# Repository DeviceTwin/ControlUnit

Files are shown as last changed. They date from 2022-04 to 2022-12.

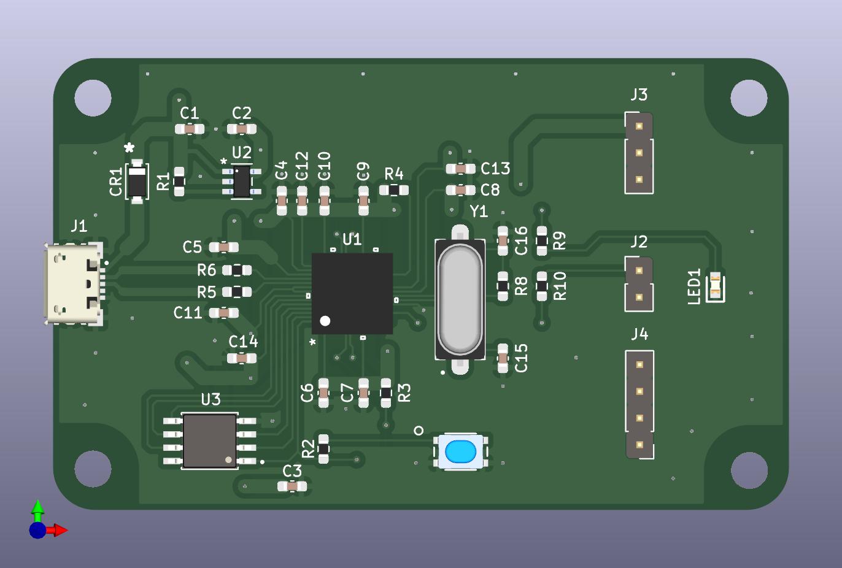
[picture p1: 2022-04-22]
Pictures/ControlUnit3DFront.jpg

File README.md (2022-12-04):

# LEDControl_HW

:one: This is my first PCB design what I ordered from real PCB factory.<br>
:two: Also this is my first PCB what I soldering using reflow owen.

Hardware of LED control unit based on:<br>
<a href="https://www.youtube.com/watch?v=kcwvuwetgEQ"
			target="_blank">Hardware Design with the RP2040: Custom PCB Based on the Raspberry Pi Pico | Digi-Key Electronics</a>

PCB design help:<br>
<a href="https://www.youtube.com/watch?v=ge6gYIENo8Q"
			target="_blank">How to Make a Raspberry Pi Compute Module 4 Carrier Board in KiCad - Part 2 | Digi-Key Electronics</a>

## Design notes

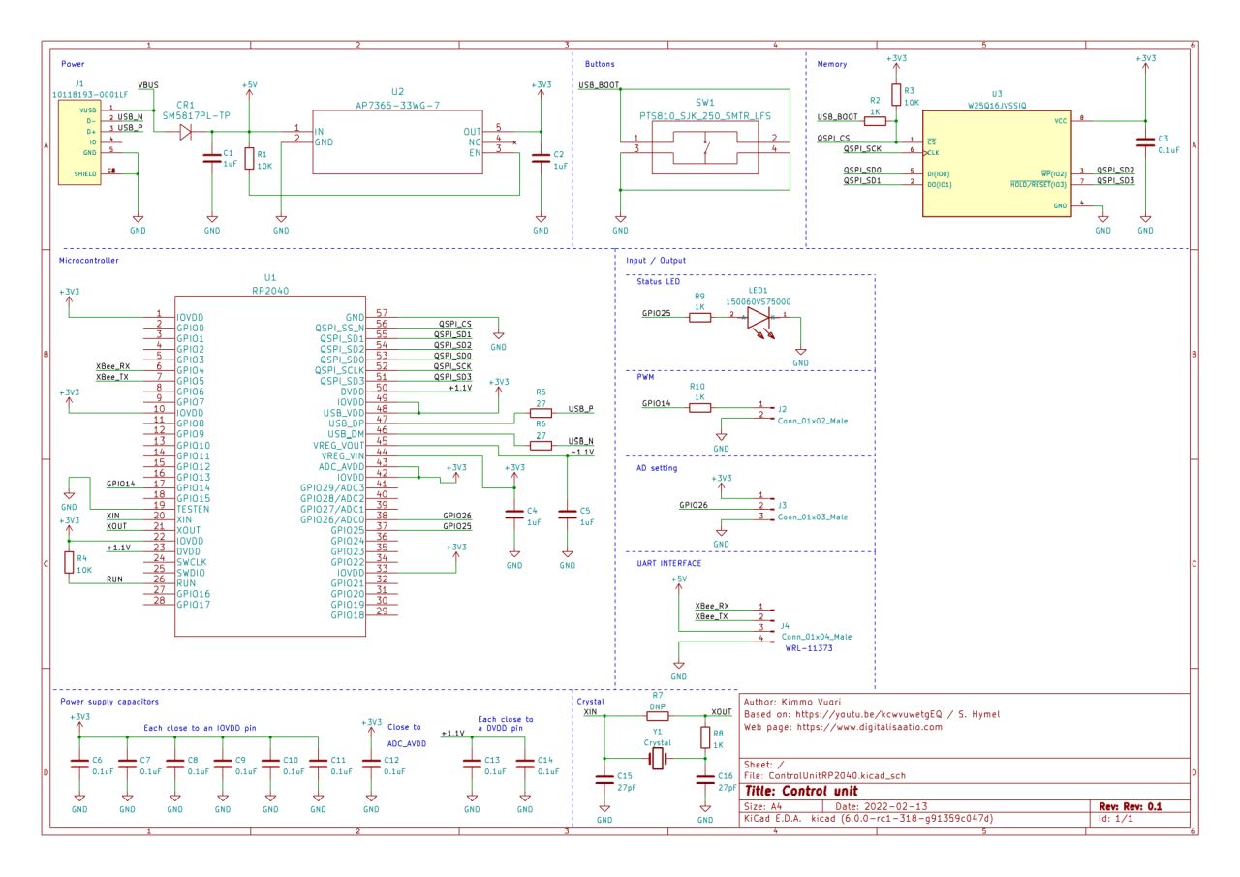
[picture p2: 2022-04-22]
Pictures/ControlUnitSchematic.jpg

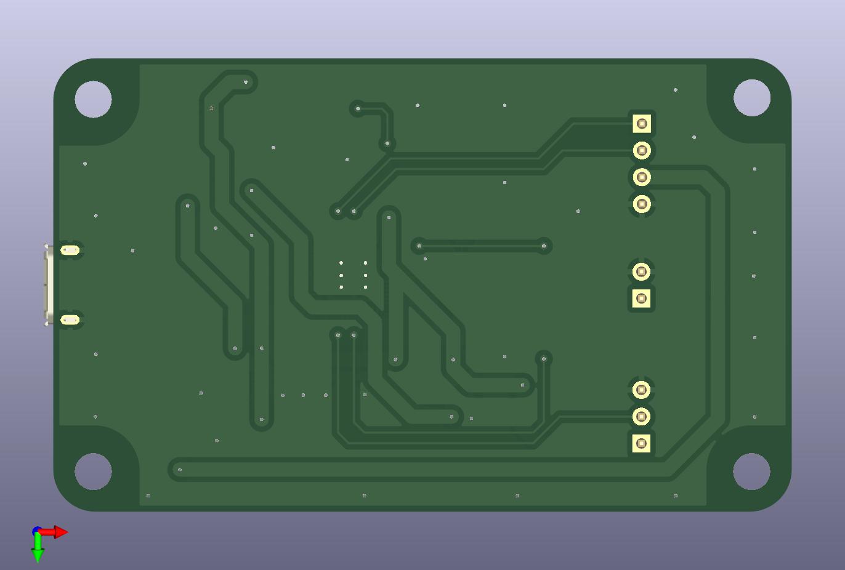
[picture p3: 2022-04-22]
Pictures/ControlUnit3DBack.jpg

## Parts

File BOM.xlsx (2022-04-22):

Reference | Quantity | Sarake1 | Sarake2 | Sarake3 | Value | Digikey | Manufacturer Product Number
C1 C2 C4 C5 | 4 | 12 | x |  | 1uF | 311-1445-1-ND | CC0603KRX5R8BB105
C15 C16 | 2 | 6 | x |  | 27pF | 399-C0603C270F3HACAUTOCT-ND | C0603C270F3HACAUTO
C3 C6 C7 C8 C9 C10 C11 C12 C13 C14 | 10 | 30 | x |  | 0.1uF | 587-1245-1-ND | TMK107BJ104KA-T
CR1 | 1 | 3 | x |  | SM5817PL-TP | SM5817PL-TPMSCT-ND | SM5817PL-TP
J1 | 1 | 3 | x |  | 10118193-0001LF | 609-4616-1-ND | 10118193-0001LF
J2 | 1 | 3 | x |  | Conn_01x02_Male | 2057-PH1-02-UA-ND | PH1-02-UA
J3 | 1 | 3 | x |  | Conn_01x03_Male | 2057-PH1-03-UA-ND | PH1-03-UA
J4 | 1 | 3 | x |  | Conn_01x04_Male | S1212EC-04-ND | PREC004SFAN-RC
LED1 | 1 | 3 | x |  | SML-310PTT86 | 511-1300-1-ND | SML-310PTT86
R1 R3 R4 | 3 | 9 | x |  | 10K | P20397TR-ND | ERJ-PB3D1002V
R2 R8 R9 R10 | 4 | 12 | x |  | 1K | P20283CT-ND | ERJ-PB3D1001V
R5 R6 | 2 | 6 | x |  | 27 | 311-27.0HRCT-ND | RC0603FR-0727RL
SW1 | 1 | 3 | x |  | PTS810_SJK_250_SMTR_LFS | CKN10503CT-ND | PTS810 SJK 250 SMTR LFS
U1 | 1 | 3 | x |  | RP2040 | 2648-SC0914(7)CT-ND | SC0914(7)
U2 | 1 | 3 | x |  | AP7365-33WG-7 | AP7365-33WG-7DICT-ND | AP7365-33WG-7
U3 | 1 | 3 | x |  | W25Q16JVSSIQ | W25Q16JVSSIQ-ND | W25Q16JVSSIQ
Y1 | 1 | 3 | x |  | Crystal | 535-10218-1-ND | ABLS-12.000MHZ-B4-T
TS391SNL | 1 | 1 | x |  | Solder paste | TS391SNL-ND | TS391SNL
Pico | 2 | 2 | x

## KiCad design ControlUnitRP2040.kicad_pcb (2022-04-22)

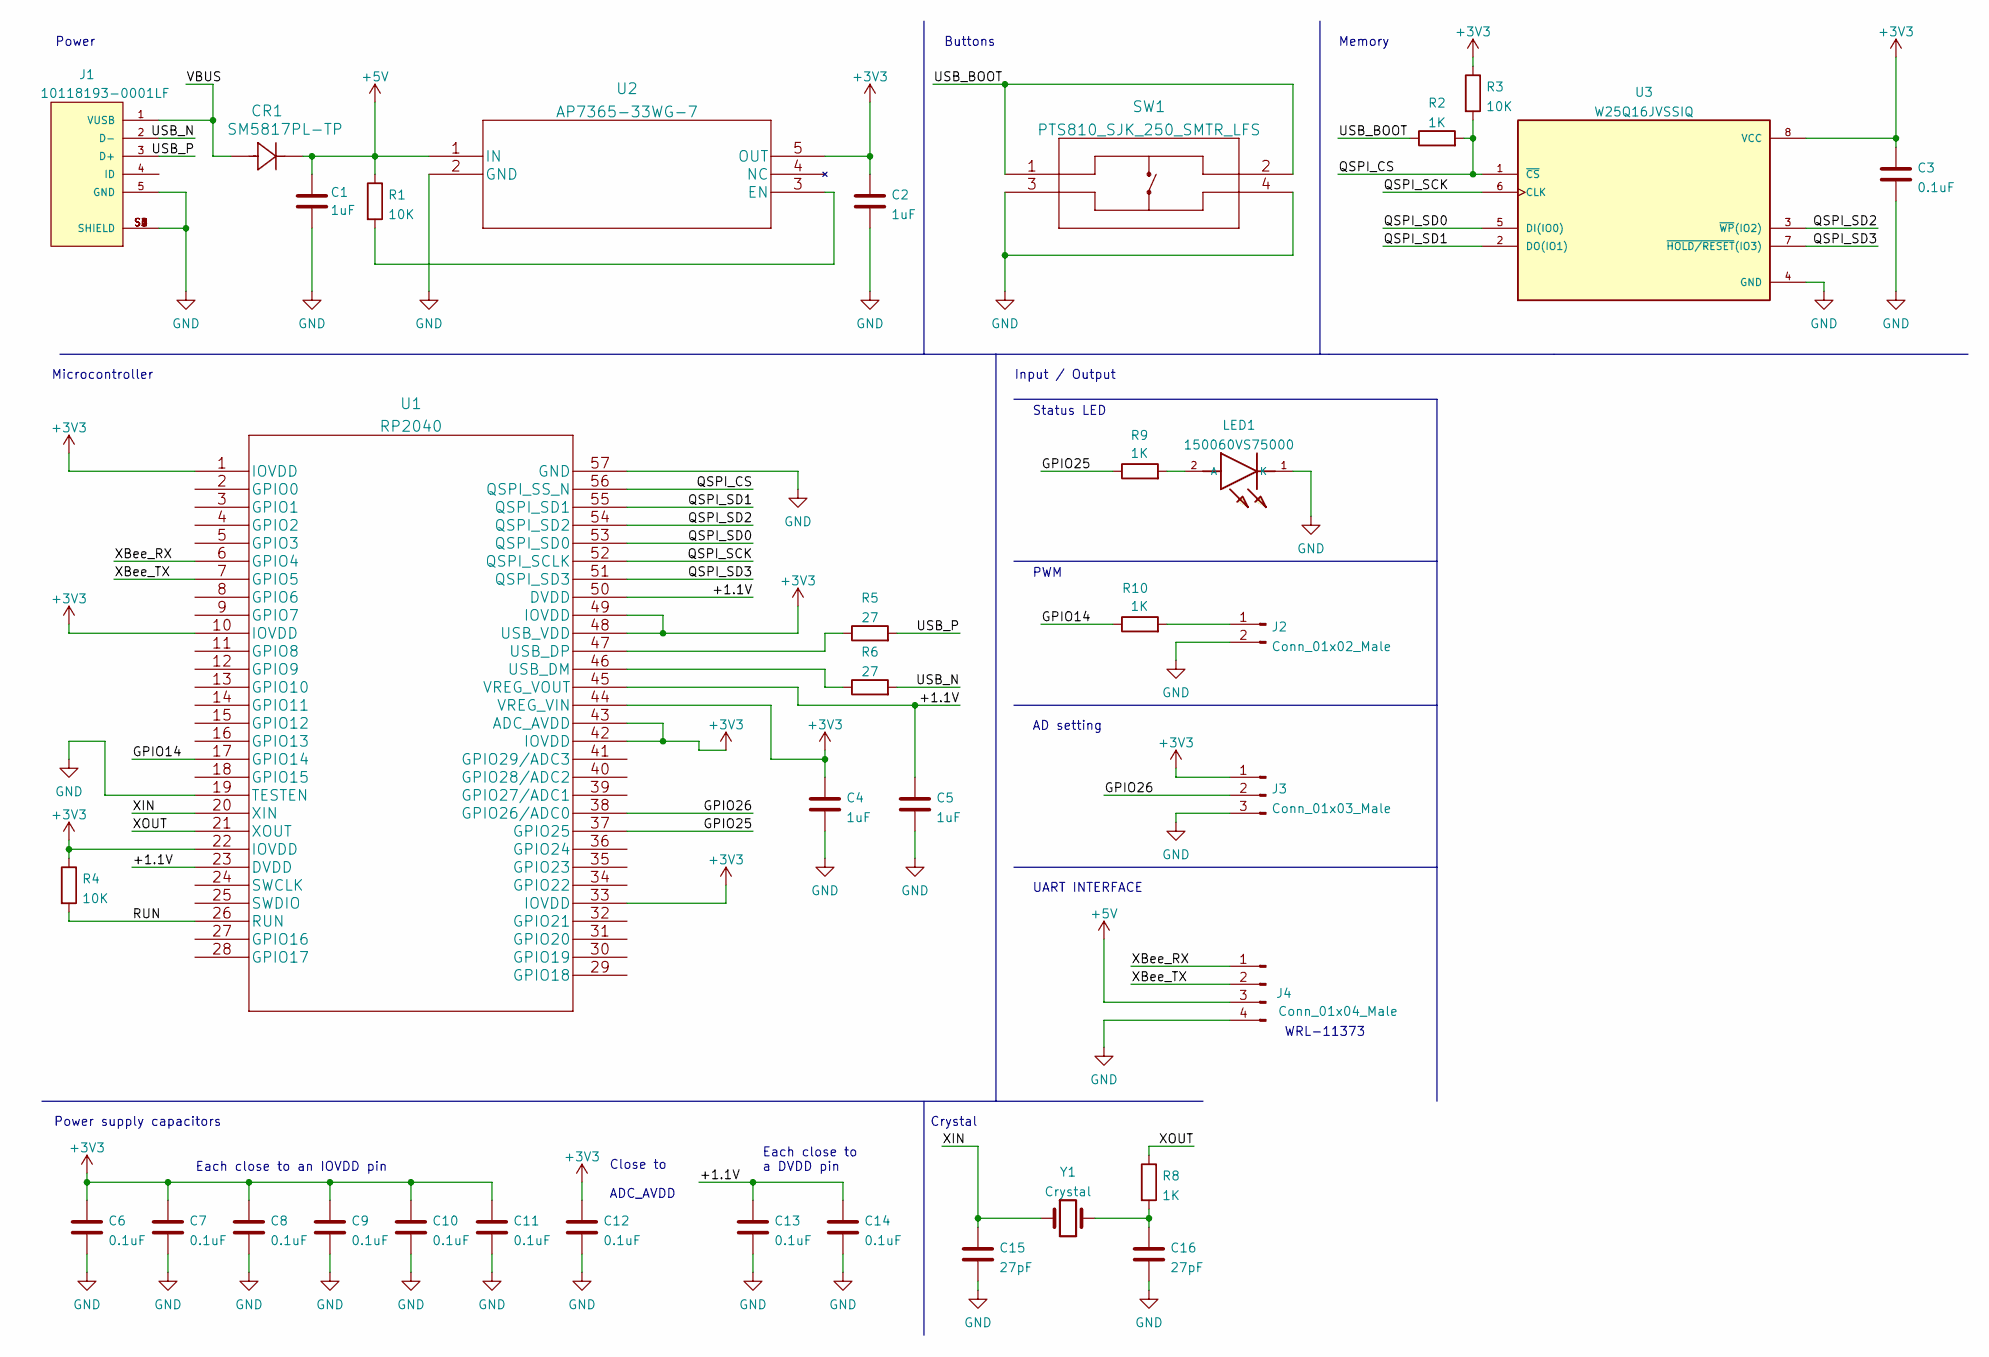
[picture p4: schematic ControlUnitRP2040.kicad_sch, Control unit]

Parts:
C1, C2, C4, C5: 1uF; C_0603_1608Metric_Pad1.08x0.95mm_HandSolder; Digikey 311-1445-1-ND
C3, C6, C7, C8, C9, C10, C11, C12, C13, C14: 0.1uF; C_0603_1608Metric_Pad1.08x0.95mm_HandSolder; Digikey 587-1245-1-ND
C15, C16: 27pF; C_0603_1608Metric_Pad1.08x0.95mm_HandSolder; Digikey 399-C0603C270F3HACAUTOCT-ND
CR1: SM5817PL-TP; Digikey SM5817PL-TPMSCT-ND
J1: 10118193-0001LF; FCI_10118193-0001LF; Digikey 609-4616-1-ND
J2: Conn_01x02_Male; PinHeader_1x02_P2.54mm_Vertical; Digikey 2057-PH1-02-UA-ND
J3: Conn_01x03_Male; PinHeader_1x03_P2.54mm_Vertical; Digikey 2057-PH1-03-UA-ND
J4: Conn_01x04_Male; PinHeader_1x04_P2.54mm_Vertical; Digikey 2057-PH1-04-UA-ND
LED1: 150060VS75000; LEDC1608X80N; Digikey 732-4980-1-ND
R1, R3, R4: 10K; R_0603_1608Metric_Pad0.98x0.95mm_HandSolder; Digikey 13-AC0603DR-0710KLCT-ND
R2, R8, R9, R10: 1K; R_0603_1608Metric_Pad0.98x0.95mm_HandSolder; Digikey P20283CT-ND
R5, R6: 27; R_0603_1608Metric_Pad0.98x0.95mm_HandSolder; Digikey 311-27.0HRCT-ND
SW1: PTS810_SJK_250_SMTR_LFS; PTS810 SJK 250 SMTR LFS; Digikey CKN10503CT-ND
U1: RP2040; Digikey 2648-SC0914(7)CT-ND
U2: AP7365-33WG-7; Digikey AP7365-33WG-7DICT-ND
U3: W25Q16JVSSIQ; SOIC127P790X216-8N; Digikey W25Q16JVSSIQ-ND
Y1: Crystal; ABLS-12.000MHZ-B4-T; Digikey 535-10218-1-ND

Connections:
+3V3: C2.1, C3.1, C4.1, C6.1, C7.1, C8.1, C9.1, C10.1, C11.1, C12.1, J3.1, R3.1, R4.1, U1.1 (IOVDD), U1.10 (IOVDD), U1.22 (IOVDD), U1.33 (IOVDD), U1.42 (IOVDD), U1.43 (ADC_AVDD), U1.44 (VREG_VIN), U1.48 (USB_VDD), U1.49 (IOVDD), U2.5 (OUT), U3.8 (VCC)
+5V: C1.1, CR1.1, J4.3, R1.1, U2.1 (IN)
/+1.1V: C5.1, C13.1, C14.1, U1.23 (DVDD), U1.45 (VREG_VOUT), U1.50 (DVDD)
/GPIO14: R10.1, U1.17 (GPIO14)
/GPIO25: R9.1, U1.37 (GPIO25)
/GPIO26: J3.2, U1.38 (GPIO26/ADC0)
/QSPI_CS: R2.2, R3.2, U1.56 (QSPI_SS_N), U3.1 (~CS)
/QSPI_SCK: U1.52 (QSPI_SCLK), U3.6 (CLK)
/QSPI_SD0: U1.53 (QSPI_SD0), U3.5 (DI(IO0))
/QSPI_SD1: U1.55 (QSPI_SD1), U3.2 (DO(IO1))
/QSPI_SD2: U1.54 (QSPI_SD2), U3.3 (~WP(IO2))
/QSPI_SD3: U1.51 (QSPI_SD3), U3.7 (~HOLD/RESET(IO3))
/RUN: R4.2, U1.26 (RUN)
/USB_BOOT: R2.1, SW1.1, SW1.2
/USB_N: J1.2 (D-), R6.2
/USB_P: J1.3 (D+), R5.2
/VBUS: CR1.2, J1.1 (VUSB)
/XBee_RX: J4.1, U1.6 (GPIO4)
/XBee_TX: J4.2, U1.7 (GPIO5)
/XIN: C15.1, U1.20 (XIN), Y1.1
/XOUT: R8.1, U1.21 (XOUT)
GND: C1.2, C2.2, C3.2, C4.2, C5.2, C6.2, C7.2, C8.2, C9.2, C10.2, C11.2, C12.2, C13.2, C14.2, C15.2, C16.2, J1.5 (GND), J1.S1 (SHIELD), J1.S2 (SHIELD), J1.S3 (SHIELD), J1.S4 (SHIELD), J1.S5 (SHIELD), J1.S6 (SHIELD), J2.2, J3.3, J4.4, LED1.1 (K), SW1.3, SW1.4, U1.19 (TESTEN), U1.57 (GND), U2.2 (GND), U3.4 (GND)
unnamed: C16.1, R8.2, Y1.2
unnamed: J2.1, R10.2
unnamed: LED1.2 (A), R9.2
unnamed: R1.2, U2.3 (EN)
unnamed: R5.1, U1.47 (USB_DP)
unnamed: R6.1, U1.46 (USB_DM)

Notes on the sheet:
Power supply capacitors
Buttons
Memory
PWM
Power
Status LED
Each close to an IOVDD pin
WRL-11373
Input / Output
Close to ADC_AVDD
Microcontroller
AD setting
Crystal
Each close to a DVDD pin
UART INTERFACE

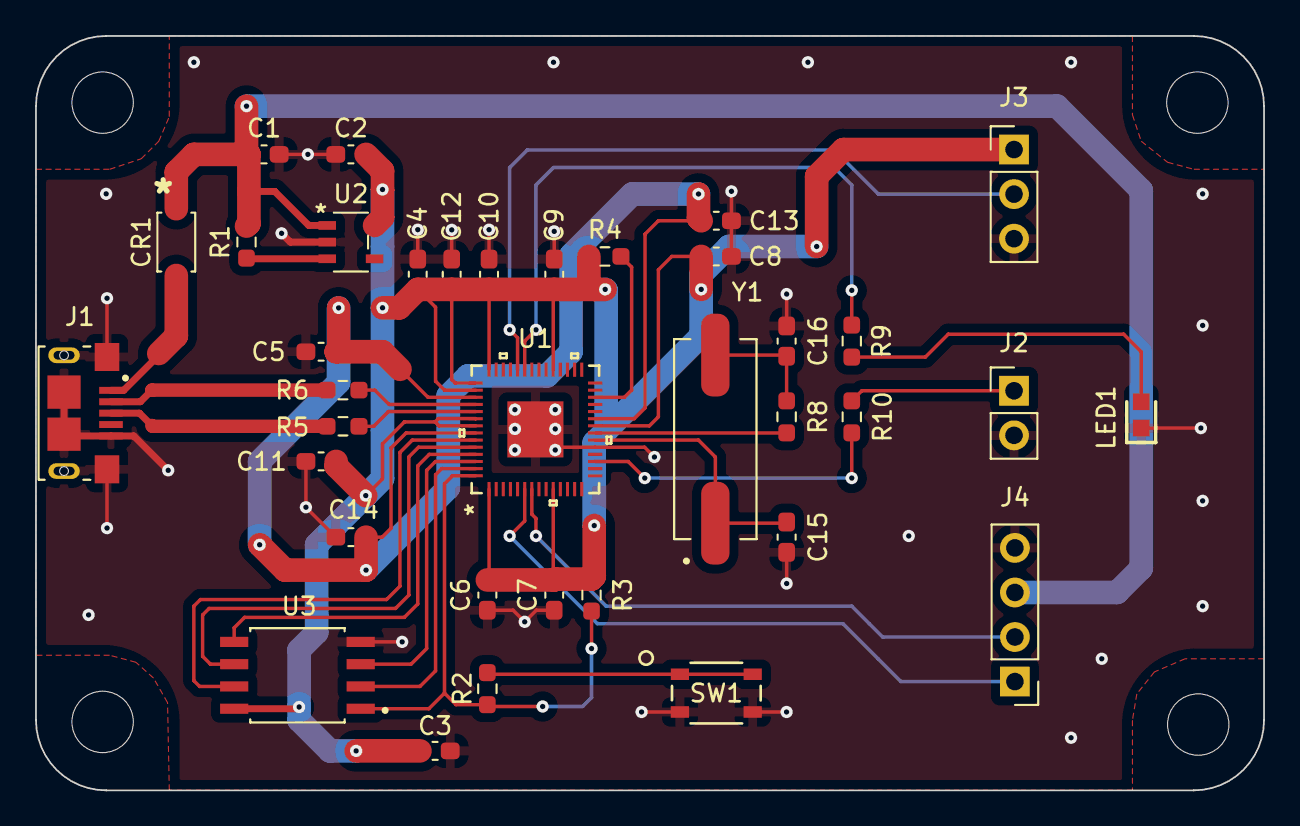
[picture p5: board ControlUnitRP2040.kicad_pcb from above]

Board: 2 copper layers, 70.0 x 43.0 mm, 40 parts (0 on the bottom side), 28 nets.

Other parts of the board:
REF1, REF2, REF3, REF4: MountingHole_3.5mm

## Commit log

2022-04-22 Version 1.0
    [BOM.xlsx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]
2022-12-04 Added PCB design help
2022-12-04 ControlUnit is now LEDControl

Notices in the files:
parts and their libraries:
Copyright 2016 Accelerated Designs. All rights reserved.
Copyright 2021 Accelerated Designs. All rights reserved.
